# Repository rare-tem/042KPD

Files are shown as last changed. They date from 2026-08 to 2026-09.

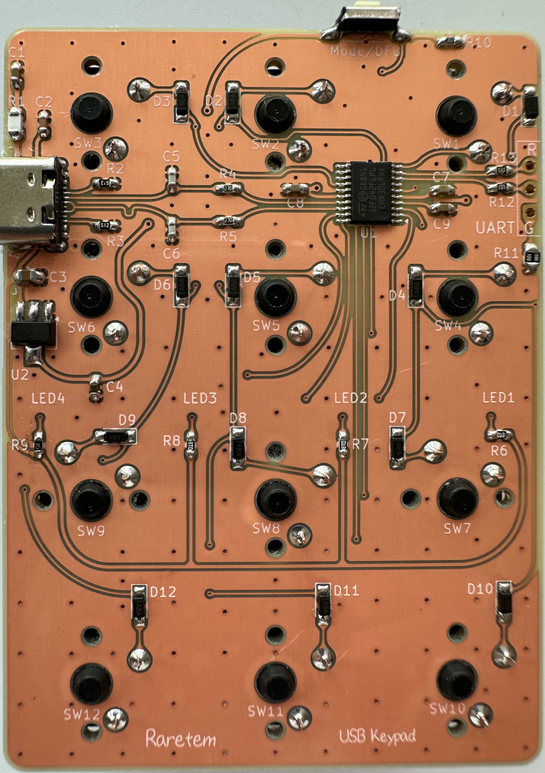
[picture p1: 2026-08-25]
img/CompSide.jpg

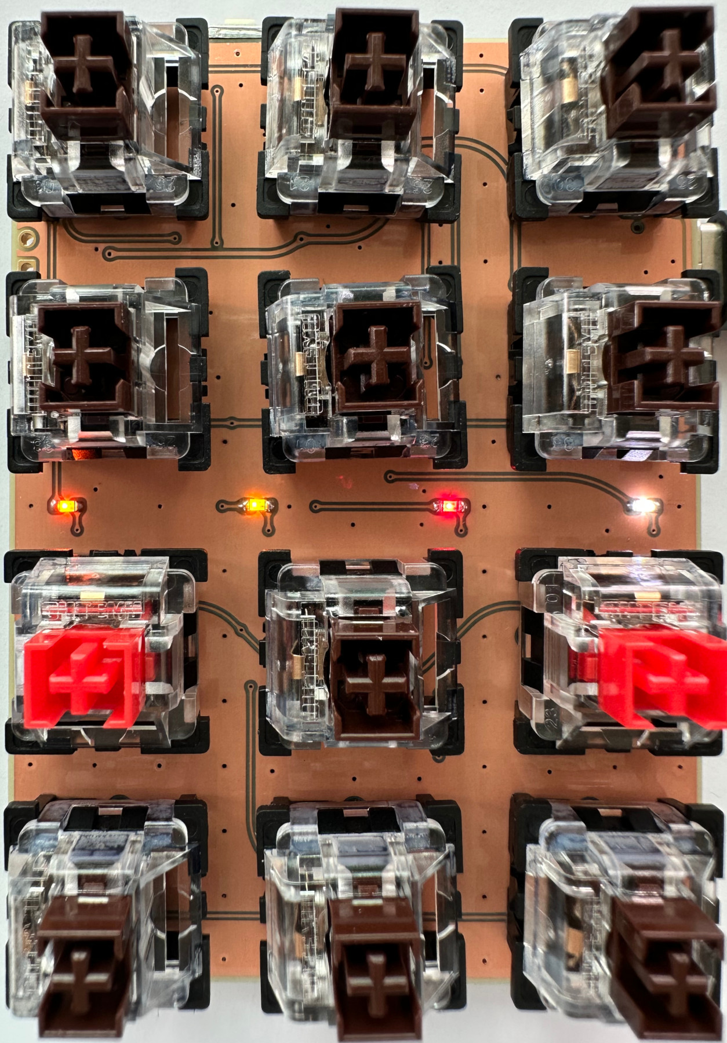
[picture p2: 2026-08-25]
img/KeySide.jpg

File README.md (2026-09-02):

This is a 4x3 USB keypad using the STM32F042F6.

Please check the photos in the "img" folder.

To switch modes, press the Mode/DFU button.

The following is the key map in Mode 1 (the leftmost LED lights up).
    Ins    Home   PgUp
    Del    End    PgDn
    Lctrl  ↑      Lshift
    ←      ↓      →

The following is the key map in Mode 2 (the second LED from the left lights up).
    7&     8*     9(
    4$     5%     6^
    1!     2@     3#
    BkSp   0)     Enter

The following is the key map in Mode 3 (the 3rd LED from the left lights up).
    F10    F11    F12
    F7     F8     F9
    F4     F5     F6
    F1     F2     F3

The rightmost LED toggles whenever it receives USB SOF. (500Hz)

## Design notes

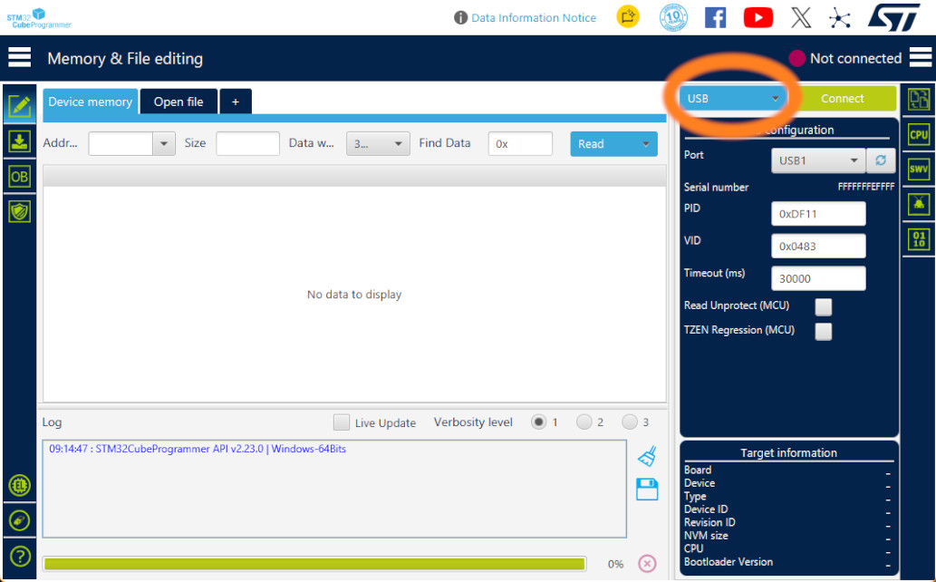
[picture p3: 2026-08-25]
img/Select USB as the target interface.jpg

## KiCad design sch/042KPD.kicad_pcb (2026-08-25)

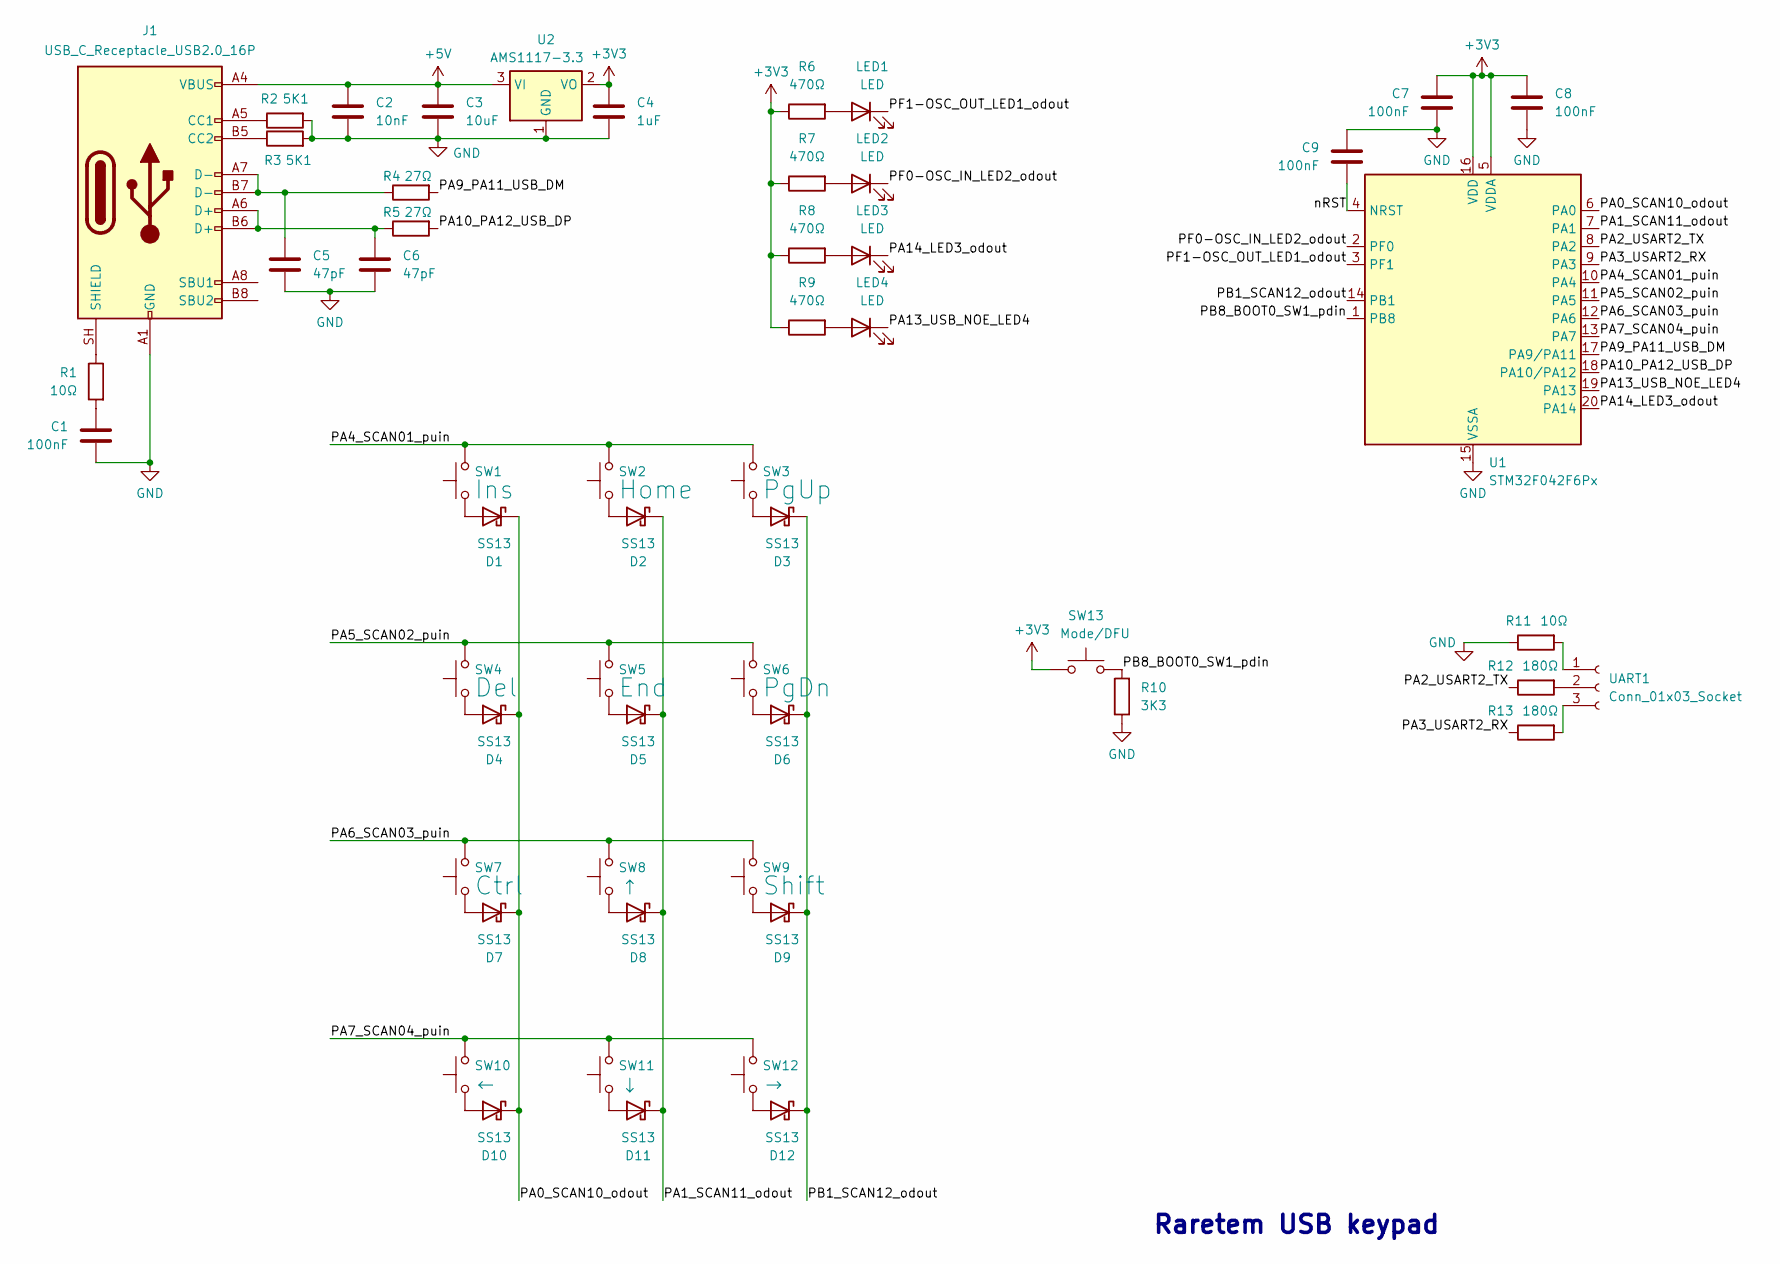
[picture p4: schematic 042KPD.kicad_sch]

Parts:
C1, C7, C8, C9: 100nF; C_0603_1608Metric_Pad1.08x0.95mm_HandSolder
C2: 10nF; C_0603_1608Metric_Pad1.08x0.95mm_HandSolder
C3: 10uF; C_0805_2012Metric_Pad1.18x1.45mm_HandSolder
C4: 1uF; C_0603_1608Metric_Pad1.08x0.95mm_HandSolder
C5, C6: 47pF; C_0603_1608Metric_Pad1.08x0.95mm_HandSolder
D1, D2, D3, D4, D5, D6, D7, D8, D9, D10, D11, D12: SS13; D_SS13
J1: USB_C_Receptacle_USB2.0_16P; USB_C_Receptacle_HH 16P TYPE-C (Y385)
LED1, LED2, LED3, LED4: LED; LED_0603_1608Metric_Pad1.05x0.95mm_HandSolder
R1, R11: 10Ω; R_0805_2012Metric_Pad1.20x1.40mm_HandSolder
R2, R3: 5K1; R_0603_1608Metric_Pad0.98x0.95mm_HandSolder
R4, R5: 27Ω; R_0603_1608Metric_Pad0.98x0.95mm_HandSolder
R6, R7, R8, R9: 470Ω; R_0603_1608Metric_Pad0.98x0.95mm_HandSolder
R10: 3K3; R_0603_1608Metric_Pad0.98x0.95mm_HandSolder
R12, R13: 180Ω; R_0603_1608Metric_Pad0.98x0.95mm_HandSolder
SW1: Ins; SW_CherryMX_PCB
SW2: Home; SW_CherryMX_PCB
SW3: PgUp; SW_CherryMX_PCB
SW4: Del; SW_CherryMX_PCB
SW5: End; SW_CherryMX_PCB
SW6: PgDn; SW_CherryMX_PCB
SW7: Ctrl; SW_CherryMX_PCB
SW8: ↑; SW_CherryMX_PCB
SW9: Shift; SW_CherryMX_PCB
SW10: ←; SW_CherryMX_PCB
SW11: ↓; SW_CherryMX_PCB
SW12: →; SW_CherryMX_PCB
SW13: Mode/DFU; SW_Tactile_SPST_6.1x1.2
U1: STM32F042F6Px; TSSOP-20_4.4x6.5mm_P0.65mm
U2: AMS1117-3.3; SOT-89-3_Handsoldering
UART1: Conn_01x03_Socket; PinHeader-03_P2.54mm

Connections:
+3V3: C4.1, C7.1, C8.1, R6.1, R7.1, R8.1, R9.1, SW13.1, U1.5 (VDDA), U1.16 (VDD), U2.2 (VO)
+5V: C2.1, C3.1, J1.A4 (VBUS), J1.A9 (VBUS), J1.B4 (VBUS), J1.B9 (VBUS), U2.3 (VI)
/PA0_SCAN10_odout: D1.1 (K), D4.1 (K), D7.1 (K), D10.1 (K), U1.6 (PA0)
/PA1_SCAN11_odout: D2.1 (K), D5.1 (K), D8.1 (K), D11.1 (K), U1.7 (PA1)
/PA2_USART2_TX: R12.1, U1.8 (PA2)
/PA3_USART2_RX: R13.1, U1.9 (PA3)
/PA4_SCAN01_puin: SW1.2, SW2.2, SW3.2, U1.10 (PA4)
/PA5_SCAN02_puin: SW4.2, SW5.2, SW6.2, U1.11 (PA5)
/PA6_SCAN03_puin: SW7.2, SW8.2, SW9.2, U1.12 (PA6)
/PA7_SCAN04_puin: SW10.2, SW11.2, SW12.2, U1.13 (PA7)
/PA9_PA11_USB_DM: R4.2, U1.17 (PA9/PA11)
/PA10_PA12_USB_DP: R5.2, U1.18 (PA10/PA12)
/PA13_USB_NOE_LED4: LED4.1 (K), U1.19 (PA13)
/PA14_LED3_odout: LED3.1 (K), U1.20 (PA14)
/PB1_SCAN12_odout: D3.1 (K), D6.1 (K), D9.1 (K), D12.1 (K), U1.14 (PB1)
/PB8_BOOT0_SW1_pdin: R10.2, SW13.2, U1.1 (PB8)
/PF0-OSC_IN_LED2_odout: LED2.1 (K), U1.2 (PF0)
/PF1-OSC_OUT_LED1_odout: LED1.1 (K), U1.3 (PF1)
/nRST: C9.1, U1.4 (NRST)
GND: C1.2, C2.2, C3.2, C4.2, C5.2, C6.2, C7.2, C8.2, C9.2, J1.A1 (GND), J1.A12 (GND), J1.B1 (GND), J1.B12 (GND), R2.2, R3.2, R10.1, R11.1, U1.15 (VSSA), U2.1 (GND)
unnamed: C1.1, R1.2
unnamed: C5.1, J1.A7 (D-), J1.B7 (D-), R4.1
unnamed: C6.1, J1.A6 (D+), J1.B6 (D+), R5.1
unnamed: D1.2 (A), SW1.1
unnamed: D2.2 (A), SW2.1
unnamed: D3.2 (A), SW3.1
unnamed: D4.2 (A), SW4.1
unnamed: D5.2 (A), SW5.1
unnamed: D6.2 (A), SW6.1
unnamed: D7.2 (A), SW7.1
unnamed: D8.2 (A), SW8.1
unnamed: D9.2 (A), SW9.1
unnamed: D10.2 (A), SW10.1
unnamed: D11.2 (A), SW11.1
unnamed: D12.2 (A), SW12.1
unnamed: J1.A5 (CC1), R2.1
unnamed: J1.B5 (CC2), R3.1
unnamed: J1.SH (SHIELD), R1.1
unnamed: LED1.2 (A), R6.2
unnamed: LED2.2 (A), R7.2
unnamed: LED3.2 (A), R8.2
unnamed: LED4.2 (A), R9.2
unnamed 42: R11.2, UART1.1; also elsewhere on the board
unnamed 43: R12.2, UART1.2; also elsewhere on the board
unnamed 44: R13.2, UART1.3; also elsewhere on the board

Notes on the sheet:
Raretem USB keypad

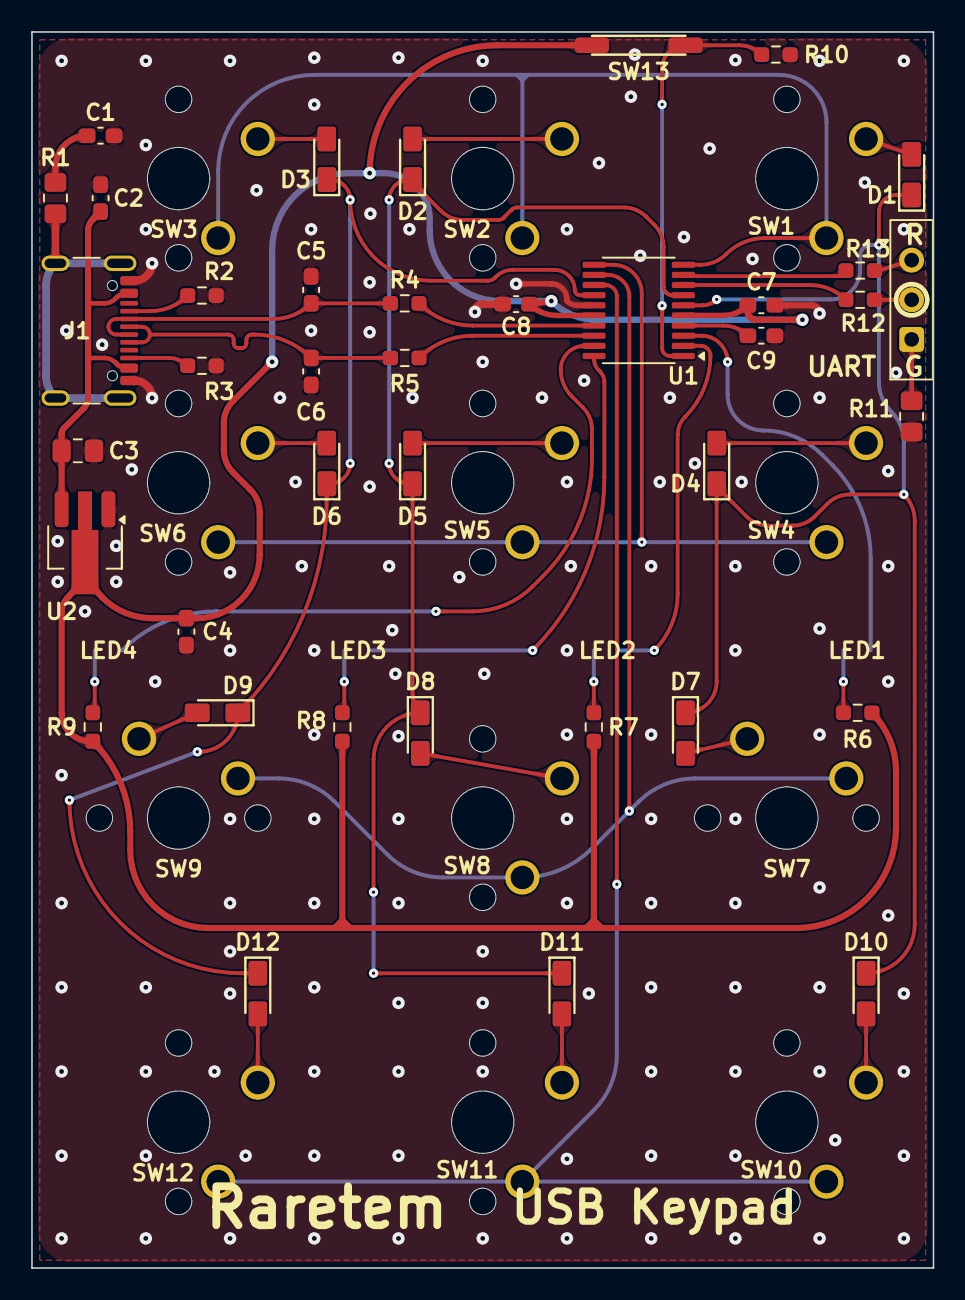
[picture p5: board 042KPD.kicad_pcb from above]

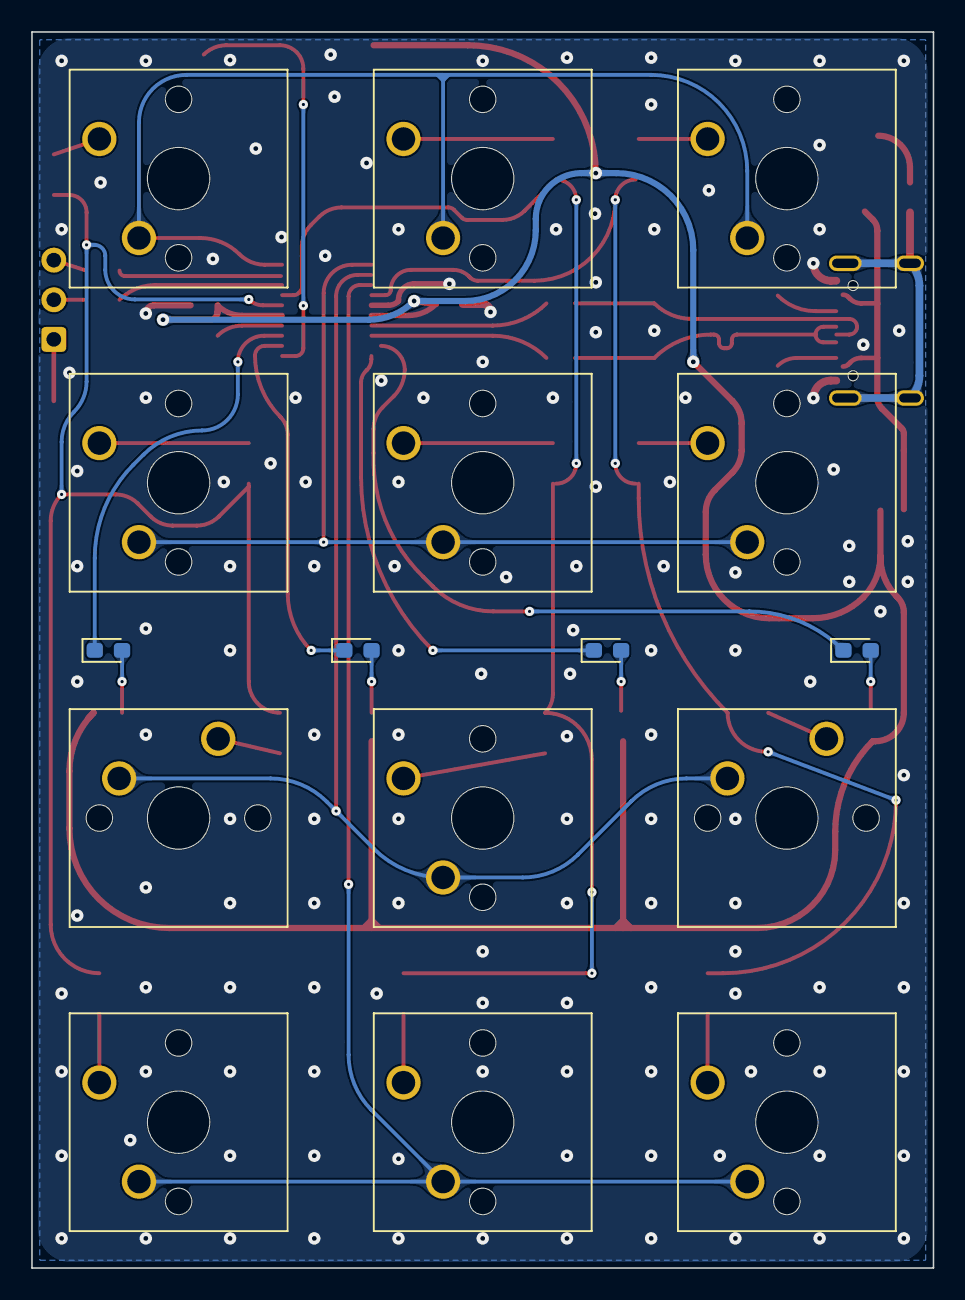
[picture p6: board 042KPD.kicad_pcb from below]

Board: 2 copper layers, 57.8 x 79.2 mm, 55 parts (16 on the bottom side), 45 nets.

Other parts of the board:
UART  G: Conn_01x03_Socket; PinHeader-03_P2.54mm

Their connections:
unnamed 42: UART G.1; also elsewhere on the board
unnamed 43: UART G.2; also elsewhere on the board
unnamed 44: UART G.3; also elsewhere on the board

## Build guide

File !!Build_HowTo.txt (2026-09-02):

** This content is for the Windows environment **

1. Please install STM32CubeCLT.
   https://www.st.com/en/development-tools/stm32cubeclt.html

2. Please open the Command Prompt.

3. Please add the folder containing "cmake.exe" to the PATH environment variable.
   ex) SET PATH=x:\yyy\***\zzz\CMake\bin;%PATH%

4. Please add the folder containing "ninja.exe" to the PATH environment variable.
   ex) SET PATH=x:\yyy\***\zzz\Ninja\bin;%PATH%

5. Please add the folder containing "starm-clang.exe" to the PATH environment variable.
   ex) SET PATH=x:\yyy\***\zzz\st-arm-clang\bin;%PATH%

6. Please chdir to the project's top-level folder (the folder containing THIS file).
   ex) cd /d x:\some\***\path\042KPD

7. Please generate the Ninja configuration and input file using CMake. (You only need to do this ONCE.)
   ex) cmake -S . -B build --toolchain cmake\starm-clang.cmake -G Ninja

8. Please chdir to the build folder.
   ex) cd build

9. Please build the project with Ninja.
   ex) ninja

10. If the "042KPD.elf" file has been created, the build was successful.

11. If you press and hold the mode button while connecting to the host via USB,
    the keypad enters device firmware update mode.

12. You can flash the firmware to the keypad using STM32CubeProgrammer
    when the keypad is in device firmware update mode. (img\Select USB as the target interface.jpg)
    https://www.st.com/en/development-tools/stm32cubeprog.html

14. If you have trouble updating the device firmware via USB, try placing a USB hub between
    the host and the keypad. (There are no issues when using the keypad as a keypad.)
    The following is an excerpt from ST's AN2606 Rev 70, page 101.
    https://www.st.com/resource/en/application_note/an2606-introduction-to-system-memory-boot-mode-on-stm32-mcus-stmicroelectronics.pdf
– USB bootloader fails on some machines using a high speed controller. The bootloader
  is detected. but then data transaction fails.
  Root causes:
  De-synchronization between USB controller and bootloader SW due to the controller
  high speed transactions. Controller high speed inter-packet delay seems not sufficient
  for the bootloader SW (based on interrupt routines) to serve all needed transactions
  (the delay needed by the BL is nearly 25 μs). Some servicing IT are missed. This
  results in a communication fail, causing Write command to fail.
  Workarounds:
  Add USB HUB between host and the MCU. This relaxes transactions inter-packet
  delay, and allows the BL SW to perform correctly the task. Use USB controller/host that
  increase inter-packet delay.
  On new designs, use DFU SW that fix the issue in user flash memory.

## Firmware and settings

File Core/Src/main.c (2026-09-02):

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
/* Includes ------------------------------------------------------------------*/
#include "main.h"
#include "gpio.h"
#include "usart.h"
#include "usb_device.h"

#include "buildDate.h"
#include "usbd_hid.h"


/* USER CODE BEGIN PV */
extern	volatile	USBD_HandleTypeDef	hUsbDeviceFS;

///	Human Interface Devices (HID) Specifications and Tools
///	https://www.usb.org/hid
/// 	https://usb.org/document-library/hid-usage-tables-17
///			https://usb.org/sites/default/files/hut1_7.pdf
uint8_t 	codeTable[3][12] = {
	{	0x49, 0x4a, 0x4b,		///	Ins    Home   PgUp
		0x4c, 0x4d, 0x4e,		///	Del    End    PgDn
		0xe0, 0x52, 0xe1,		///	Lctrl  ↑      Lshift
		0x50, 0x51, 0x4f	},	///	←      ↓      →

	{	0x24, 0x25, 0x26,		///	7&     8*     9(
		0x21, 0x22, 0x23,		///	4$     5%     6^
		0x1e, 0x1f, 0x20,		///	1!     2@     3#
		0x2a, 0x27, 0x28	},	///	BkSp   0)     Enter

	{	0x43, 0x44, 0x45,		///	F10    F11    F12
		0x40, 0x41, 0x42,		///	F7     F8     F9
		0x3d, 0x3e, 0x3f,		///	F4     F5     F6
		0x3a, 0x3b, 0x3c	},	///	F1     F2     F3
};

volatile	uint8_t 	usbSOFflag,	///	++ed in USB SOF (USBD_LL_SOF() in usbd_core.c)
						lockLED;	///	Num Lock, Caps Lock, Scroll Lock, ... (USBD_HID_Init(), usbdHIDdataOut() in usbd_hid.c)
uint8_t 	u8, v8, prevLled, scanline, kbuf[12], mbuf, keyMode, usartBuf[16];
uint16_t	keyStat, prevKstat;
uint32_t	sysID, eTme;
uint64_t	reportBuff;

/* USER CODE END PV */

void SystemClock_Config(void);
/**
 * @brief  The application entry point.
 * @retval int
 */
int main(void)
{
/* MCU Configuration--------------------------------------------------------*/

/* Reset of all peripherals, Initializes the Flash interface and the Systick. */
	HAL_Init();

/* Configure the system clock */
	SystemClock_Config();

/* USER CODE BEGIN SysInit */
	SysTick->CTRL = 0;	///	Disable sysTick
/* USER CODE END SysInit */

/* Initialize all configured peripherals */
	MX_GPIO_Init();	///	All LEDs ON, Prepare for first scan

	__HAL_RCC_DMA1_CLK_ENABLE();	///MX_DMA_Init();
	MX_USART2_UART_Init();
	usart2xmitDMA(bldatePtr, 35);	///	Greetings

	LL_AHB1_GRP1_EnableClock(LL_AHB1_GRP1_PERIPH_CRC);	///MX_CRC_Init();
	CRC->CR |= CRC_CR_RESET;
	while (CRC->CR & CRC_CR_RESET)
		__NOP();
	CRC->DR = *((uint32_t *)DBGMCU_BASE);
	CRC->DR = *((uint32_t *)(UID_BASE + 8));
	CRC->DR = *((uint32_t *)(UID_BASE + 4));
	CRC->DR = *((uint32_t *)(UID_BASE));
	sysID = CRC->DR;

	while (DMA1_Channel4->CNDTR)
		__NOP();
	MX_USB_DEVICE_Init();
	while (hUsbDeviceFS.dev_state != USBD_STATE_CONFIGURED)
		__NOP();

/* USER CODE BEGIN 2 */
	LL_GPIO_SetOutputPin(PF0_OSC_IN_LED2_odout_GPIO_Port, PF0_OSC_IN_LED2_odout_Pin);	///	LED2 off
	LL_GPIO_SetOutputPin(PA14_LED3_odout_GPIO_Port, PA14_LED3_odout_Pin);	///	LED3 off
	usartBuf[1] = usartBuf[8] = usartBuf[15] = ' ';
/* USER CODE END 2 */

/* Infinite loop */
/* USER CODE BEGIN WHILE */
	while (hUsbDeviceFS.dev_state != USBD_STATE_DEFAULT)
	{
		for (eTme = 0; !usbSOFflag; )
			if (eTme >= 0x400000)
				LL_GPIO_SetOutputPin(PA13_LED4_odout_GPIO_Port, PA13_LED4_odout_Pin);
			else
				eTme++;
/* USER CODE END WHILE */

		usbSOFflag--;
		LL_GPIO_TogglePin(PA13_LED4_odout_GPIO_Port, PA13_LED4_odout_Pin);

		///	Check lock LEDs
		if (prevLled != lockLED && !(DMA1_Channel4->CNDTR))
		{
			///	Notifies the status of the lock LEDs via USART2
			usartBuf[0] =
			usartBuf[2] =
			usartBuf[3] =
			usartBuf[13] =
			usartBuf[14] = ' ';

			usartBuf[4] = (lockLED & (1 << 0)) ? '#' : '~';	///	Num lock
			usartBuf[5] = (lockLED & (1 << 1)) ? '#' : '~';	///	Caps lock
			usartBuf[6] = (lockLED & (1 << 2)) ? '#' : '~';	///	Scroll lock
			usartBuf[7] = (lockLED & (1 << 3)) ? '#' : '~';
			usartBuf[9] = (lockLED & (1 << 4)) ? '#' : '~';
			usartBuf[10] = (lockLED & (1 << 5)) ? '#' : '~';
			usartBuf[11] = (lockLED & (1 << 6)) ? '#' : '~';
			usartBuf[12] = (lockLED & (1 << 7)) ? '#' : '~';
			usart2xmitDMA(usartBuf, 16);

			prevLled = lockLED;
		}

		///	Check mode button
		mbuf <<= 1;
		if (LL_GPIO_IsInputPinSet(PB8_BOOT0_SW1_pdin_GPIO_Port, PB8_BOOT0_SW1_pdin_Pin))
			mbuf |= 1;
		if (!mbuf)
			keyStat &= 0x7fff;
		else if (mbuf == 0xff && !(keyStat & 0x8000))
		{
			keyStat |= 0x8000;

			///	Keypad mode change (inc)
			switch (keyMode)
			{
				case 0:
					LL_GPIO_SetOutputPin(PF1_OSC_OUT_LED1_odout_GPIO_Port,
							PF1_OSC_OUT_LED1_odout_Pin);	///	LED1 off
					LL_GPIO_ResetOutputPin(PF0_OSC_IN_LED2_odout_GPIO_Port,
							PF0_OSC_IN_LED2_odout_Pin);	///	LED2 On
					keyMode++;
					break;
				case 1:
					LL_GPIO_SetOutputPin(PF0_OSC_IN_LED2_odout_GPIO_Port,
							PF0_OSC_IN_LED2_odout_Pin);	///	LED2 off
					LL_GPIO_ResetOutputPin(PA14_LED3_odout_GPIO_Port,
							PA14_LED3_odout_Pin);	///	LED3 On
					keyMode++;
					break;
				default:
					LL_GPIO_SetOutputPin(PA14_LED3_odout_GPIO_Port,
							PA14_LED3_odout_Pin);	///	LED3 off
					LL_GPIO_ResetOutputPin(PF1_OSC_OUT_LED1_odout_GPIO_Port,
							PF1_OSC_OUT_LED1_odout_Pin);	///	LED1 On
					keyMode = 0;
					break;
			}
		}

		///	Check USART2 Rx
		if (keyStat == prevKstat && (USART2->ISR & USART_ISR_RXNE))
		{
			if ((u8 = USART2->RDR) <= ' ')
			{
				if (!(DMA1_Channel4->CNDTR))
					usart2xmitDMA(bldatePtr, 35);	///	Notifies firmware information via USART2
			}
			else if (u8 & 1)	///	Keypad mode change (inc)
			{
				switch (keyMode)
				{
					case 0:
						LL_GPIO_SetOutputPin(PF1_OSC_OUT_LED1_odout_GPIO_Port,
								PF1_OSC_OUT_LED1_odout_Pin);	///	LED1 off
						LL_GPIO_ResetOutputPin(PF0_OSC_IN_LED2_odout_GPIO_Port,
								PF0_OSC_IN_LED2_odout_Pin);	///	LED2 On
						keyMode++;
						break;
					case 1:
						LL_GPIO_SetOutputPin(PF0_OSC_IN_LED2_odout_GPIO_Port,
								PF0_OSC_IN_LED2_odout_Pin);	///	LED2 off
						LL_GPIO_ResetOutputPin(PA14_LED3_odout_GPIO_Port,
								PA14_LED3_odout_Pin);	///	LED3 On
						keyMode++;
						break;
					default:
						LL_GPIO_SetOutputPin(PA14_LED3_odout_GPIO_Port,
								PA14_LED3_odout_Pin);	///	LED3 off
						LL_GPIO_ResetOutputPin(PF1_OSC_OUT_LED1_odout_GPIO_Port,
								PF1_OSC_OUT_LED1_odout_Pin);	///	LED1 On
						keyMode = 0;
						break;
				}
			}
			else	///	Keypad mode change (dec)
			{
				switch (keyMode)
				{
					case 0:
						LL_GPIO_SetOutputPin(PF1_OSC_OUT_LED1_odout_GPIO_Port,
								PF1_OSC_OUT_LED1_odout_Pin);	///	LED1 off
						LL_GPIO_ResetOutputPin(PA14_LED3_odout_GPIO_Port,
								PA14_LED3_odout_Pin);	///	LED3 On
						keyMode = 2;
						break;
					case 1:
						LL_GPIO_SetOutputPin(PF0_OSC_IN_LED2_odout_GPIO_Port,
								PF0_OSC_IN_LED2_odout_Pin);	///	LED2 off
						LL_GPIO_ResetOutputPin(PF1_OSC_OUT_LED1_odout_GPIO_Port,
								PF1_OSC_OUT_LED1_odout_Pin);	///	LED1 On
						keyMode--;
						break;
					default:
						LL_GPIO_SetOutputPin(PA14_LED3_odout_GPIO_Port,
								PA14_LED3_odout_Pin);	///	LED3 off
						LL_GPIO_ResetOutputPin(PF0_OSC_IN_LED2_odout_GPIO_Port,
								PF0_OSC_IN_LED2_odout_Pin);	///	LED2 On
						keyMode--;
						break;
				}
			}
		}

		///	Scan and check keys
		u8 = GPIOA->IDR;	///	LOW bit means the key is ON.
		switch (scanline)
		{
			case 0:
				///	Prepare for next scan
				LL_GPIO_SetOutputPin(PA0_SCAN10_odout_GPIO_Port, PA0_SCAN10_odout_Pin);
				LL_GPIO_ResetOutputPin(PA1_SCAN11_odout_GPIO_Port, PA1_SCAN11_odout_Pin);

				if ( !(kbuf[0] = ((kbuf[0] << 1) | (u8 & 0x10))) )			///	Row1,Col1: Ins
					keyStat |= (1 << 0);
				else if (kbuf[0] == 0xf0)
					keyStat &= ~(1 << 0);

				if ( !(kbuf[3] = ((kbuf[3] << 1) | ((u8 >> 1) & 0x10))) )	///	Row2,Col1: Del
					keyStat |= (1 << 3);
				else if (kbuf[3] == 0xf0)
					keyStat &= ~(1 << 3);

				if ( !(kbuf[6] = ((kbuf[6] << 1) | ((u8 >> 2) & 0x10))) )	///	Row3,Col1: Lctrl
					keyStat |= (1 << 6);
				else if (kbuf[6] == 0xf0)
					keyStat &= ~(1 << 6);

				if ( !(kbuf[9] = ((kbuf[9] << 1) | ((u8 >> 3) & 0x10))) )	///	Row4,Col1: ←
					keyStat |= (1 << 9);
				else if (kbuf[9] == 0xf0)
					keyStat &= ~(1 << 9);

				scanline++;
				break;

			case 1:
				///	Prepare for next scan
				LL_GPIO_SetOutputPin(PA1_SCAN11_odout_GPIO_Port, PA1_SCAN11_odout_Pin);
				LL_GPIO_ResetOutputPin(PB1_SCAN12_odout_GPIO_Port, PB1_SCAN12_odout_Pin);

				if ( !(kbuf[1] = ((kbuf[1] << 1) | (u8 & 0x10))) )			///	Row1,Col2: Home
					keyStat |= (1 << 1);
				else if (kbuf[1] == 0xf0)
					keyStat &= ~(1 << 1);

				if ( !(kbuf[4] = ((kbuf[4] << 1) | ((u8 >> 1) & 0x10))) )	///	Row2,Col2: End
					keyStat |= (1 << 4);
				else if (kbuf[4] == 0xf0)
					keyStat &= ~(1 << 4);

				if ( !(kbuf[7] = ((kbuf[7] << 1) | ((u8 >> 2) & 0x10))) )	///	Row3,Col2: ↑
					keyStat |= (1 << 7);
				else if (kbuf[7] == 0xf0)
					keyStat &= ~(1 << 7);

				if ( !(kbuf[10] = ((kbuf[10] << 1) | ((u8 >> 3) & 0x10))) )	///	Row4,Col2: ↓
					keyStat |= (1 << 10);
				else if (kbuf[10] == 0xf0)
					keyStat &= ~(1 << 10);

				scanline++;
				break;

			default:
				///	Prepare for next scan
				LL_GPIO_SetOutputPin(PB1_SCAN12_odout_GPIO_Port, PB1_SCAN12_odout_Pin);
				LL_GPIO_ResetOutputPin(PA0_SCAN10_odout_GPIO_Port, PA0_SCAN10_odout_Pin);

				if ( !(kbuf[2] = ((kbuf[2] << 1) | (u8 & 0x10))) )			///	Row1,Col3: PgUp
					keyStat |= (1 << 2);
				else if (kbuf[2] == 0xf0)
					keyStat &= ~(1 << 2);

				if ( !(kbuf[5] = ((kbuf[5] << 1) | ((u8 >> 1) & 0x10))) )	///	Row2,Col3: PgDn
					keyStat |= (1 << 5);
				else if (kbuf[5] == 0xf0)
					keyStat &= ~(1 << 5);

				if ( !(kbuf[8] = ((kbuf[8] << 1) | ((u8 >> 2) & 0x10))) )	///	Row3,Col3: Lshift
					keyStat |= (1 << 8);
				else if (kbuf[8] == 0xf0)
					keyStat &= ~(1 << 8);

				if ( !(kbuf[11] = ((kbuf[11] << 1) | ((u8 >> 3) & 0x10))) )	///	Row4,Col3: →
					keyStat |= (1 << 11);
				else if (kbuf[11] == 0xf0)
					keyStat &= ~(1 << 11);
				
				scanline = 0;
				break;
		}

		///	Check for report
		if (keyStat != prevKstat)
		{
			reportBuff = (uint64_t)0;
			for (u8 = 0, v8 = 2; u8 < 12 && v8 < (2 + 6); u8++)
			{
				if (keyStat & (1 << u8))
				{
					if (codeTable[keyMode][u8] >= 0xe0)	///	modifier
					{
						if (codeTable[keyMode][u8] <= 0xe7)
							((uint8_t *)&reportBuff)[0] |=
									1 << (codeTable[keyMode][u8] - 0xe0);
					}
					else
						((uint8_t *)&reportBuff)[v8++] = codeTable[keyMode][u8];
				}
			}
			if (u8 < 12)	///	Phantom state
			{
				((uint16_t *)&reportBuff)[1] = 0x0101;
				((uint32_t *)&reportBuff)[1] = 0x01010101;
			}

			while ( ((USBD_HID_HandleTypeDef *)hUsbDeviceFS.pClassData)
					->state != HID_IDLE )
				__NOP();
			USBD_HID_SendReport((USBD_HandleTypeDef *)&hUsbDeviceFS,
					(uint8_t *)&reportBuff, sizeof (reportBuff));

			if (!(DMA1_Channel4->CNDTR))
			{
				///	Reports the status of the keys to USART2
				if (u8 < 12)	///	Phantom state
					usartBuf[0] = (keyStat & 0x8000) ? '@' : '=';	///	Mode button
				else
					usartBuf[0] = (keyStat & 0x8000) ? '*' : '-';	///	Mode button
				usartBuf[2] = (keyStat & (1 << 0)) ? '0' : '-';
				usartBuf[3] = (keyStat & (1 << 1)) ? '1' : '-';
				usartBuf[4] = (keyStat & (1 << 2)) ? '2' : '-';
				usartBuf[5] = (keyStat & (1 << 3)) ? '3' : '-';
				usartBuf[6] = (keyStat & (1 << 4)) ? '4' : '-';
				usartBuf[7] = (keyStat & (1 << 5)) ? '5' : '-';
				usartBuf[9] = (keyStat & (1 << 6)) ? '6' : '-';
				usartBuf[10] = (keyStat & (1 << 7)) ? '7' : '-';
				usartBuf[11] = (keyStat & (1 << 8)) ? '8' : '-';
				usartBuf[12] = (keyStat & (1 << 9)) ? '9' : '-';
				usartBuf[13] = (keyStat & (1 << 10)) ? 'A' : '-';
				usartBuf[14] = (keyStat & (1 << 11)) ? 'B' : '-';
				usart2xmitDMA(usartBuf, 16);
			}

			prevKstat = keyStat;
		}

/* USER CODE BEGIN 3 */
	}

	__NOP();
	__disable_irq();
	__NOP();
	for (;;)
	{
		__NOP();
		NVIC_SystemReset();
		__NOP();
	}

/* USER CODE END 3 */
}

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
static	uint16_t	errLen;
static	const	char	*errMsg;

/**
 * @brief  This function is executed in case of error occurrence.
 * @retval None
 */
void Error_Handler(const char *errWhere)
{
/* USER CODE BEGIN Error_Handler_Debug */
/* User can add his own implementation to report the HAL error return state */
	__disable_irq();

	LL_GPIO_ResetOutputPin(GPIOF,
			PF1_OSC_OUT_LED1_odout_Pin | PF0_OSC_IN_LED2_odout_Pin);	///	LED 1,2 On
	LL_GPIO_SetOutputPin(GPIOA,
			PA14_LED3_odout_Pin | PA13_LED4_odout_Pin);	///	LED 3,4 off

	if (errWhere)
		for (errMsg = errWhere, errLen = 0; *errMsg; errMsg++, errLen++)
			;	///	errLen = strlen(errWhere)
	else
		errLen = 0;

	if (errLen && !(DMA1_Channel4->CNDTR))
		usart2xmitDMA(errWhere, errLen);

	for (eTme = 0; ; )
	{
		if (!(++eTme & 0x1fffff))
		{
			LL_GPIO_TogglePin(GPIOF,
					PF1_OSC_OUT_LED1_odout_Pin | PF0_OSC_IN_LED2_odout_Pin);
			LL_GPIO_TogglePin(GPIOA,
					PA14_LED3_odout_Pin | PA13_LED4_odout_Pin);

			if (errLen && !(DMA1_Channel4->CNDTR))
				usart2xmitDMA(errWhere, errLen);
		}
	}
/* USER CODE END Error_Handler_Debug */
}
#ifdef USE_FULL_ASSERT
/**
 * @brief  Reports the name of the source file and the source line number
 *         where the assert_param error has occurred.
 * @param  file: pointer to the source file name
 * @param  line: assert_param error line source number
 * @retval None
 */
void assert_failed(uint8_t *file, uint32_t line)
{
/* USER CODE BEGIN 6 */
/* User can add his own implementation to report the file name and line number,
   ex: printf("Wrong parameters value: file %s on line %d\r\n", file, line) */
/* USER CODE END 6 */
}
#endif	/* USE_FULL_ASSERT */

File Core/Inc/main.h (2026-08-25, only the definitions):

#define PB8_BOOT0_SW1_pdin_Pin LL_GPIO_PIN_8
#define PB8_BOOT0_SW1_pdin_GPIO_Port GPIOB
#define PF0_OSC_IN_LED2_odout_Pin LL_GPIO_PIN_0
#define PF0_OSC_IN_LED2_odout_GPIO_Port GPIOF
#define PF1_OSC_OUT_LED1_odout_Pin LL_GPIO_PIN_1
#define PF1_OSC_OUT_LED1_odout_GPIO_Port GPIOF
#define PA0_SCAN10_odout_Pin LL_GPIO_PIN_0
#define PA0_SCAN10_odout_GPIO_Port GPIOA
#define PA1_SCAN11_odout_Pin LL_GPIO_PIN_1
#define PA1_SCAN11_odout_GPIO_Port GPIOA
#define PA2_USART2_TX_Pin LL_GPIO_PIN_2
#define PA2_USART2_TX_GPIO_Port GPIOA
#define PA3_USART2_RX_Pin LL_GPIO_PIN_3
#define PA3_USART2_RX_GPIO_Port GPIOA
#define PA4_SCAN01_puin_Pin LL_GPIO_PIN_4
#define PA4_SCAN01_puin_GPIO_Port GPIOA
#define PA5_SCAN02_puin_Pin LL_GPIO_PIN_5
#define PA5_SCAN02_puin_GPIO_Port GPIOA
#define PA6_SCAN03_puin_Pin LL_GPIO_PIN_6
#define PA6_SCAN03_puin_GPIO_Port GPIOA
#define PA7_SCAN04_puin_Pin LL_GPIO_PIN_7
#define PA7_SCAN04_puin_GPIO_Port GPIOA
#define PB1_SCAN12_odout_Pin LL_GPIO_PIN_1
#define PB1_SCAN12_odout_GPIO_Port GPIOB
#define PA9_PA11_USB_DM_Pin LL_GPIO_PIN_11
#define PA9_PA11_USB_DM_GPIO_Port GPIOA
#define PA10_PA12_USB_DP_Pin LL_GPIO_PIN_12
#define PA10_PA12_USB_DP_GPIO_Port GPIOA
#define PA13_LED4_odout_Pin LL_GPIO_PIN_13
#define PA13_LED4_odout_GPIO_Port GPIOA
#define PA14_LED3_odout_Pin LL_GPIO_PIN_14
#define PA14_LED3_odout_GPIO_Port GPIOA

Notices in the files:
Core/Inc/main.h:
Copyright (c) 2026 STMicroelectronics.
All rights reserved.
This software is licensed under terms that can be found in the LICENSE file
